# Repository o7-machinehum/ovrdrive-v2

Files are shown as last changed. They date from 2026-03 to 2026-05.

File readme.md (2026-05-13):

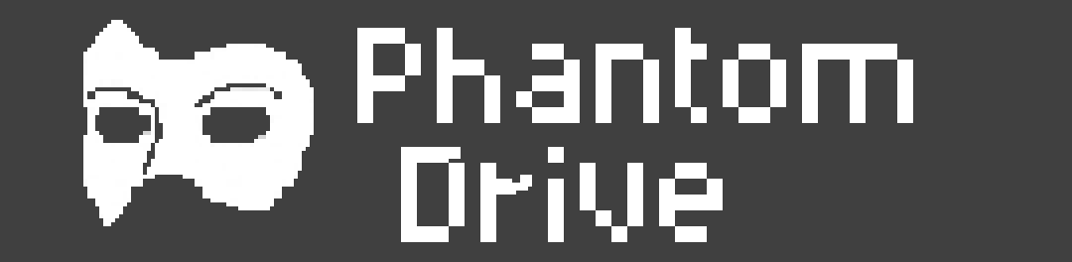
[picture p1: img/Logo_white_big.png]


Phantomdrive is open source encrypted USB drive with a stealth mechanism to hide its second partition. To decrypt it you must create a file called unlock.txt containing your password in the format `password:addpasswordhere`, this is used to derive a AES-256 key. The drive automatically unmounts itself, remounts the remaining disk and encrypts and decrypts in place. It uses CH569W SoC, which has USB3, SDIO and an AES hardware block. It is programmable over USB using the `wch-ch56x-isp` library.

``` bash
|-- ee             # Hardware files
|-- Makefile
|-- readme.md      # This files
|-- test           # Test the cypto components
|-- ref            # Reference docs
|-- src            # Firmware
|-- tests          # Verification scripts
|-- wch-ch56x-bsp  # Board support package
`-- wch-ch56x-isp  # Programming software
```

# Getting Started
``` bash
git submodule update --init --recursive --checkout --force
cd wch-ch56x-isp
make # Build the ISP tool
```

## Install the toolchain
The HydraUSB3 project requires a patched GCC that supports the
`WCH-Interrupt-fast` interrupt attribute. Download the xpack GCC from the HydraUSB3 project:

```bash
cd /tmp
curl -sL -o riscv-gcc-xpack.tar.gz \
  "https://github.com/hydrausb3/riscv-none-elf-gcc-xpack/releases/download/12.2.0-1/xpack-riscv-none-elf-gcc-12.2.0-1-linux-x64.tar.gz"
tar xzf riscv-gcc-xpack.tar.gz
sudo cp -r xpack-riscv-none-elf-gcc-12.2.0-1/* /usr/local/
```

## Debugging
```
make UART=1 # Enable UART
make UART=1 DEBUG_USB=1 # Enable USB Debugging
```

## Build and Flashing the project
``` bash
make
# Remove flash drive
# While holding boot button, plug in
./wch-ch56x-isp/wch-ch56x-isp -d=off # This is needed just one to disable debug mode
make flash
```

## Unlocking Drive
``` bash
sudo echo "password:YourPasswordHere13245" > /mnt/unlock.txt
```

# Releasing the hardware
``` bash
./scripts/release_hardware.sh
```

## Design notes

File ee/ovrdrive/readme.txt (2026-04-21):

Ovrdrive
--------
Size :	36.6 x 15 mm
Layer : 4 Layers
Material : FR-4: TG150
Thickness : 0.6 mm
Min track/spacing : 4/4mil
Min hole size : 0.2mm
Solder mask : Black
Silkscreen : White
Edge connector : No
Surface finish : HASL lead free
Via process : Tenting vias
Finished copper : 1 oz Cu (Inner Copper:1 oz)
Remove product No. : Yes

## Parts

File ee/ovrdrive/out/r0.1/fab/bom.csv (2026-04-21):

Designator | Value | Footprint | Quantity | Part Number
C1,C2,C5-C7,C9,C11-C13 | 22uF | Capacitor_SMD:C_0402_1005Metric | 9 | CL05A226MQ5N6J8
C3,C4,C8,C10,C14-C18,C21-C23,C26-C28 | 100nF | Capacitor_SMD:C_0402_1005Metric | 15 | CL05B104KP5NNNC
C19,C20 | 15pF | Capacitor_SMD:C_0402_1005Metric | 2 | CL05C150JB5NNNC
C24,C25 | 2.2uF | Capacitor_SMD:C_0402_1005Metric | 2 | CL05A225MQ5NNNC
J2 | USB3_A | Connector_USB:USB3_A_Plug_Wuerth_692112030100_Horizontal | 1 | 692112030100
J4 | Micro_SD_Card_Det_Hirose_DM3AT | Connector_Card:microSD_HC_Hirose_DM3AT-SF-PEJM5 | 1 | DM3AT-SF-PEJM5
L1,L2 | 2.2uH | Inductor_SMD:L_Changjiang_FTC303015D | 2 | SRN3015-2R2M
R1,R2,R4,R5 | 100k | Capacitor_SMD:C_0402_1005Metric | 4 | RC0402FR-07100KL
R3 | 450k | Capacitor_SMD:C_0402_1005Metric | 1 | RC0402FR-07453KL
RN1,RN2 | 47k | Resistor_SMD:R_Array_Concave_4x0402 | 2 | CAT10-473J4LF
SW1 | SW_Push | Button_Switch_SMD:SW_Push_SPST_NO_Alps_SKRK | 1 | SKRKAEE020
U1 | CH569W | Package_DFN_QFN:QFN-68-1EP_8x8mm_P0.4mm_EP5.2x5.2mm | 1 | CH569W
U2,U3 | TLV62569DBV | Package_TO_SOT_SMD:SOT-23-5 | 2 | TLV62569DBV
Y2 | 30Mhz | Crystal:Crystal_SMD_3225-4Pin_3.2x2.5mm | 1 | ABM8-30.000MHZ-12-B1U-T

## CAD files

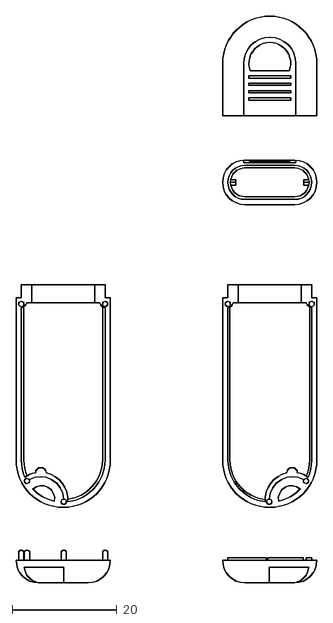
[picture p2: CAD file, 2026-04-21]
mech/LK-USB06.dxf
57.4 x 108.1

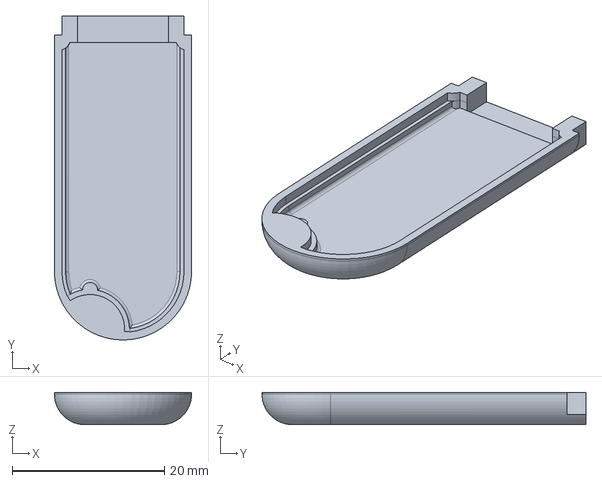
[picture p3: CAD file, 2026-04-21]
mech/case-Model.step
18.0 x 42.5 x 4.25 mm

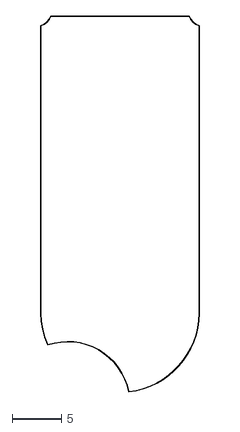
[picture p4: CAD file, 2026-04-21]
mech/LK-USB06_PCB_Outline.dxf
16.0 x 38.0

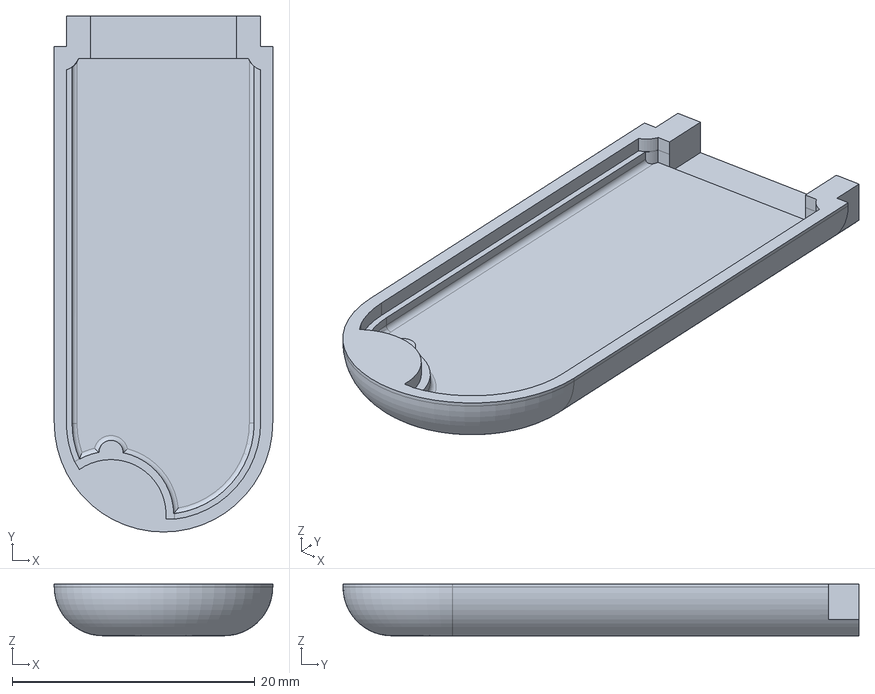
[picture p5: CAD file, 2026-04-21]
mech/case.FCStd
18.0 x 42.5 x 4.25 mm

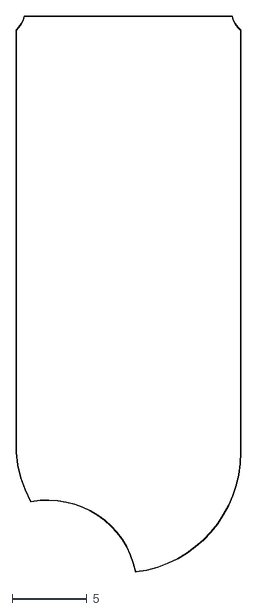
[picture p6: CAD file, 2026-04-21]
mech/outline-ModelSketch.dxf
15.0 x 37.2

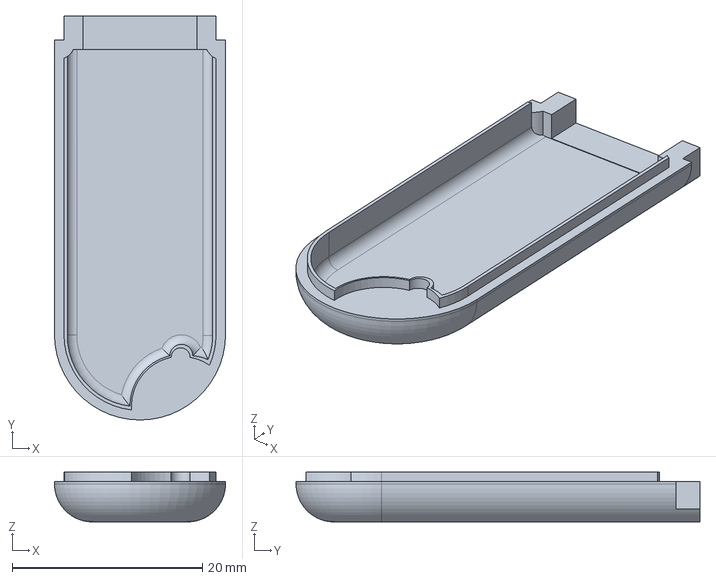
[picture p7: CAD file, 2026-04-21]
mech/case_top.FCStd
18.0 x 42.5 x 5.25 mm

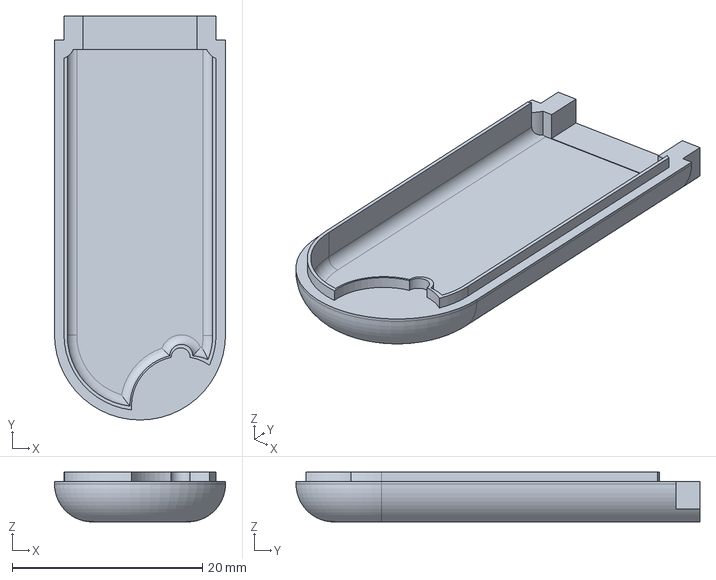
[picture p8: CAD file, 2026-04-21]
mech/case_top-Model.step
18.0 x 42.5 x 5.25 mm

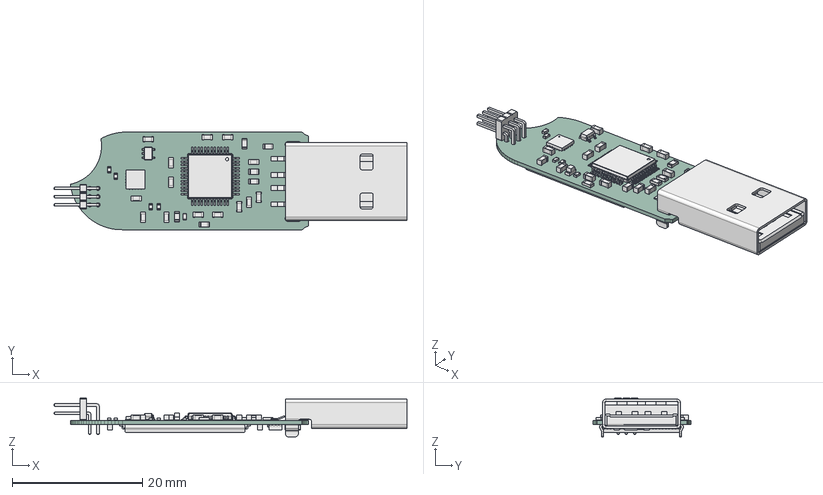
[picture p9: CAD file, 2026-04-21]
mech/pcb.FCStd
54.3 x 15.0 x 5.97 mm
ovrdrive PCB002

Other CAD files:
mech/LK-USB15.dwg
mech/LK-USB08.dwg
mech/LK-USB09.dwg
mech/LK-USB05.dwg
mech/LK-USB10.dwg
mech/ovrdrive.FCStd
mech/outline.FCStd
mech/LK-USB06.dwg

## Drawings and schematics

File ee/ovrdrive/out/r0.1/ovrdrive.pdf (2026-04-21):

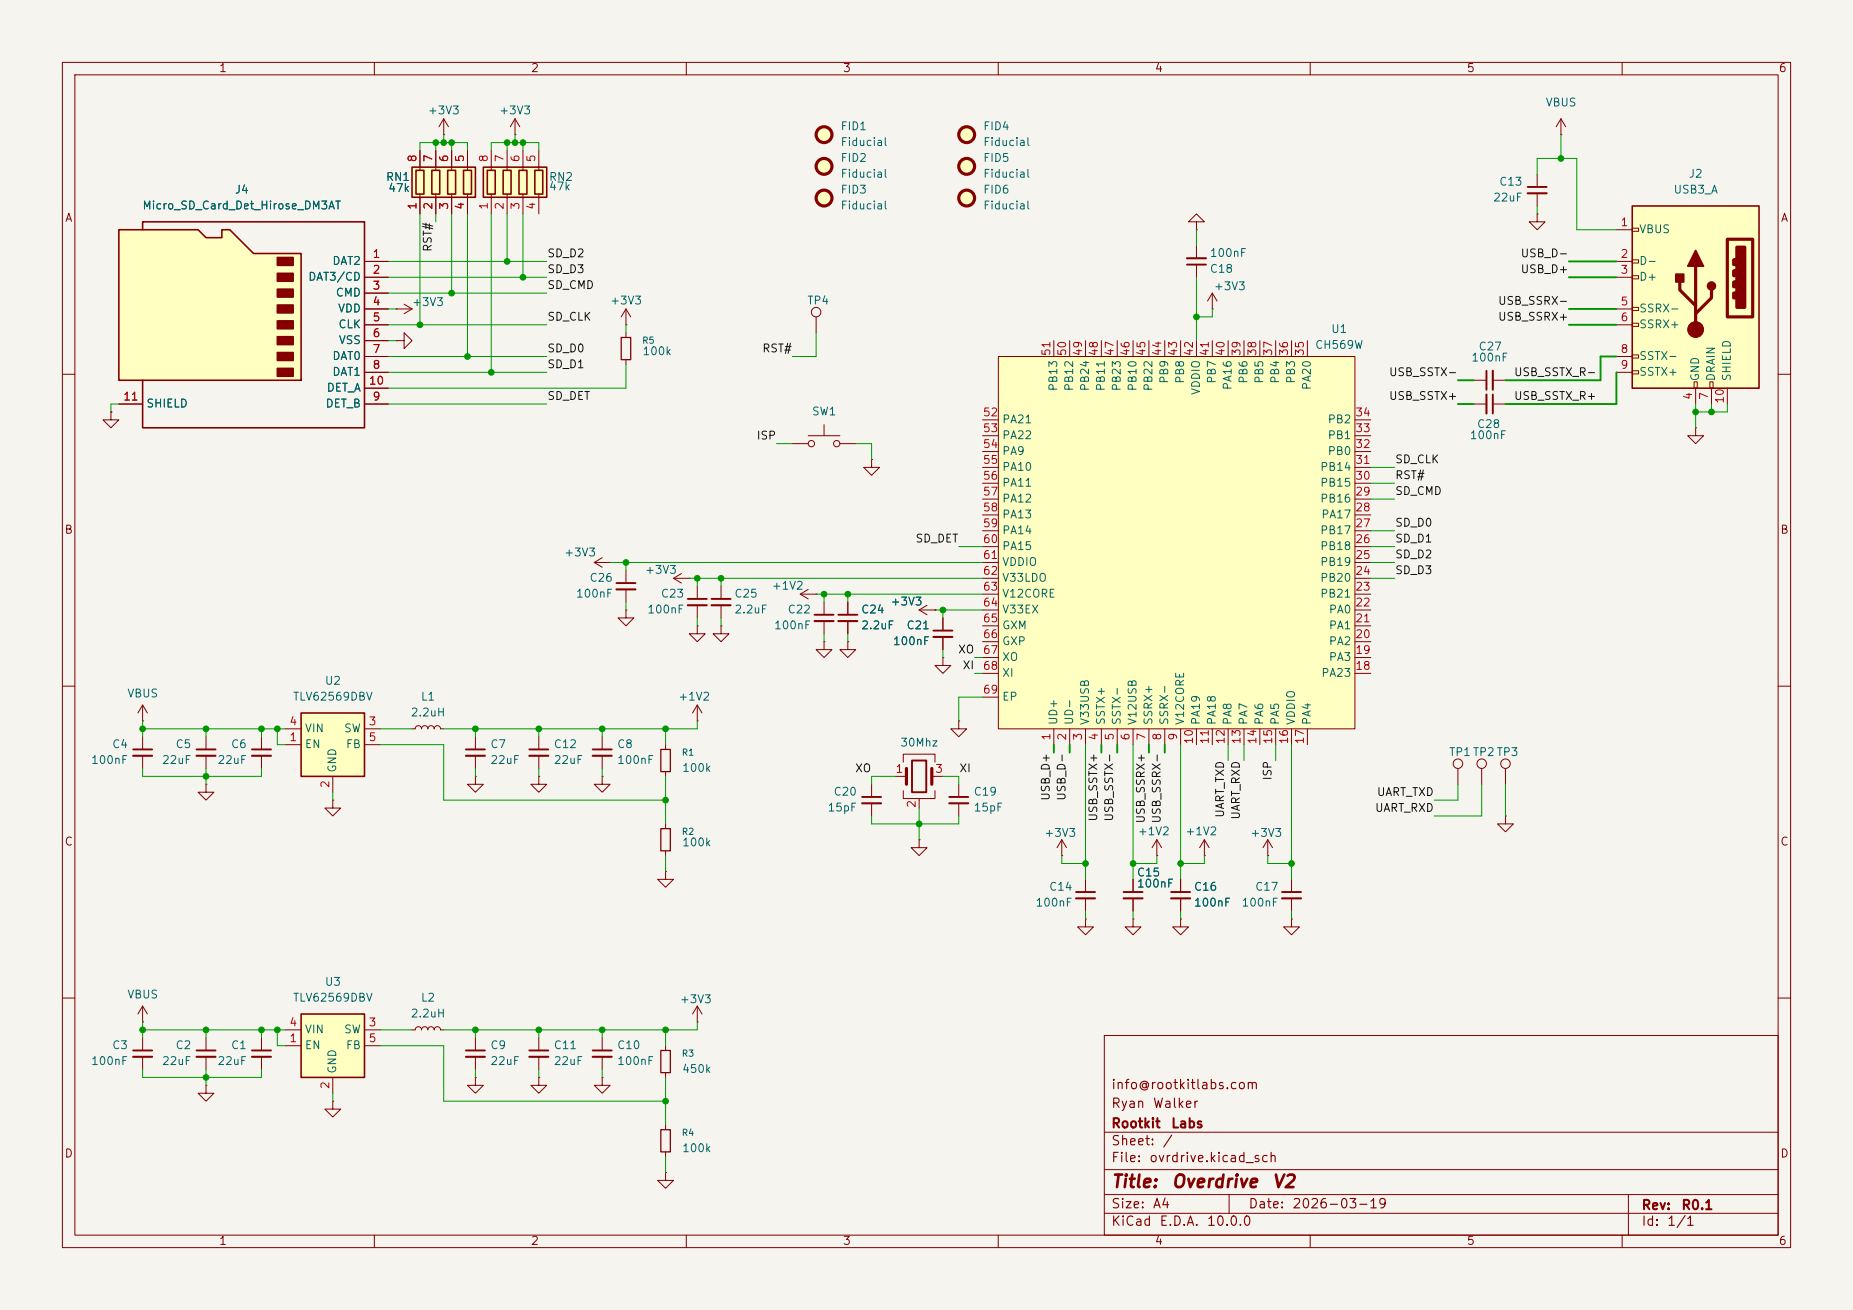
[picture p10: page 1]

info@rootkitlabs.com
Rootkit Labs Ryan Walker

Size: A4 | Rev: R0.1

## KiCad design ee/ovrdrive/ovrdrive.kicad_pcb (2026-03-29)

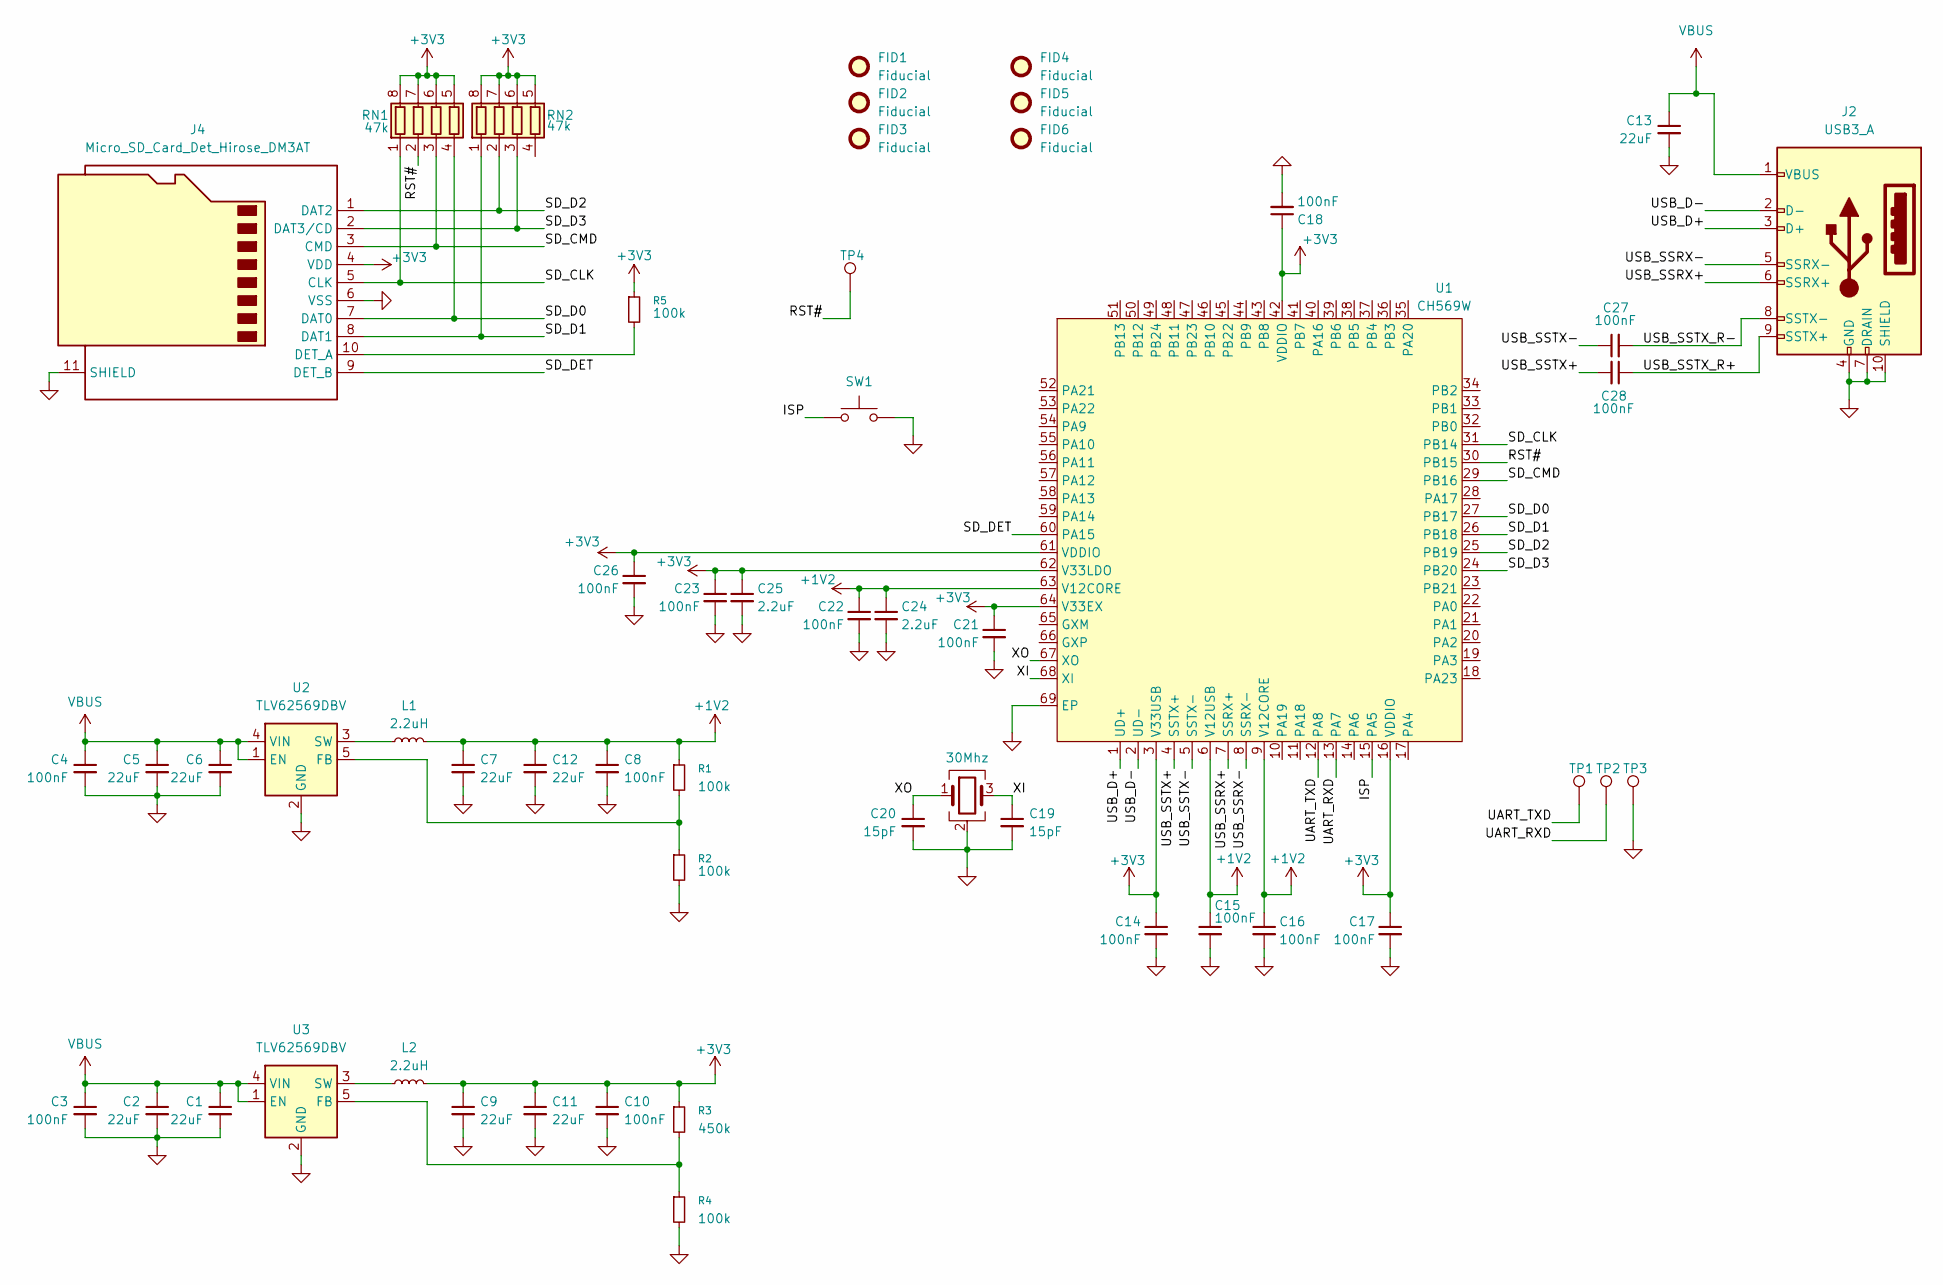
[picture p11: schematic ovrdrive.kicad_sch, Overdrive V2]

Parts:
C1, C2, C5, C6, C7, C9, C11, C12, C13: 22uF; C_0402_1005Metric; MPN CL05A226MQ5N6J8
C3, C4, C8, C10, C14, C15, C16, C17, C18, C21, C22, C23, C26, C27, C28: 100nF; C_0402_1005Metric; MPN CL05B104KP5NNNC
C19, C20: 15pF; C_0402_1005Metric; MPN CL05C150JB5NNNC
C24, C25: 2.2uF; C_0402_1005Metric; MPN CL05A225MQ5NNNC
FID1, FID2, FID3, FID4, FID5, FID6: Fiducial; Fiducial_0.5mm_Mask1mm; MPN DNP
J2: USB3_A; USB3_A_Plug_Wuerth_692112030100_Horizontal; MPN 692112030100
J4: Micro_SD_Card_Det_Hirose_DM3AT; microSD_HC_Hirose_DM3AT-SF-PEJM5; MPN DM3AT-SF-PEJM5
L1, L2: 2.2uH; L_Changjiang_FTC303015D; MPN SRN3015-2R2M
R1, R2, R4, R5: 100k; C_0402_1005Metric; MPN RC0402FR-07100KL
R3: 450k; C_0402_1005Metric; MPN RC0402FR-07453KL
RN1, RN2: 47k; R_Array_Concave_4x0402; MPN CAT10-473J4LF
SW1: SW_Push; SW_Push_SPST_NO_Alps_SKRK; MPN SKRKAEE020
TP1, TP2, TP3, TP4: TestPoint; TestPoint_Pad_1.0x1.0mm; MPN DNP
U1: CH569W; QFN-68-1EP_8x8mm_P0.4mm_EP5.2x5.2mm; MPN CH569W
U2, U3: TLV62569DBV; SOT-23-5; MPN TLV62569DBV
Y2: 30Mhz; Crystal_SMD_3225-4Pin_3.2x2.5mm; MPN ABM8-30.000MHZ-12-B1U-T

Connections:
+1V2: C7.1, C8.1, C12.1, C15.1, C16.1, C22.1, C24.1, L1.2, R1.1, U1.6 (V12USB), U1.9 (V12CORE), U1.63 (V12CORE)
+3V3: C9.1, C10.1, C11.1, C14.1, C17.1, C18.1, C21.1, C23.1, C25.1, C26.1, J4.4 (VDD), L2.2, R3.1, R5.1, RN1.5 (R4.2), RN1.6 (R3.2), RN1.7 (R2.2), RN1.8 (R1.2), RN2.5 (R4.2), RN2.6 (R3.2), RN2.7 (R2.2), RN2.8 (R1.2), U1.3 (V33USB), U1.16 (VDDIO), U1.42 (VDDIO), U1.61 (VDDIO), U1.62 (V33LDO), U1.64 (V33EX)
/ISP: SW1.1, U1.15 (PA5)
/RST#: RN1.2 (R2.1), TP4.1 (1_1), U1.30 (PB15)
/SD_CLK: J4.5 (CLK), RN1.1 (R1.1), U1.31 (PB14)
/SD_CMD: J4.3 (CMD), RN1.3 (R3.1), U1.29 (PB16)
/SD_D0: J4.7 (DAT0), RN1.4 (R4.1), U1.27 (PB17)
/SD_D1: J4.8 (DAT1), RN2.1 (R1.1), U1.26 (PB18)
/SD_D2: J4.1 (DAT2), RN2.2 (R2.1), U1.25 (PB19)
/SD_D3: J4.2 (DAT3/CD), RN2.3 (R3.1), U1.24 (PB20)
/SD_DET: J4.9 (DET_B), U1.60 (PA15)
/UART_RXD: TP2.1 (1_1), U1.13 (PA7)
/UART_TXD: TP1.1 (1_1), U1.12 (PA8)
/USB_D+: J2.3 (D+), U1.1 (UD+)
/USB_D-: J2.2 (D-), U1.2 (UD-)
/USB_SSRX+: J2.6 (SSRX+), U1.7 (SSRX+)
/USB_SSRX-: J2.5 (SSRX-), U1.8 (SSRX-)
/USB_SSTX+: C28.2, U1.4 (SSTX+)
/USB_SSTX-: C27.1, U1.5 (SSTX-)
/USB_SSTX_R+: C28.1, J2.9 (SSTX+)
/USB_SSTX_R-: C27.2, J2.8 (SSTX-)
/XI: C19.1, U1.68 (XI), Y2.3
/XO: C20.1, U1.67 (XO), Y2.1
GND: C1.2, C2.2, C3.2, C4.2, C5.2, C6.2, C7.2, C8.2, C9.2, C10.2, C11.2, C12.2, C13.2, C14.2, C15.2, C16.2, C17.2, C18.2, C19.2, C20.2, C21.2, C22.2, C23.2, C24.2, C25.2, C26.2, J2.4 (GND), J2.7 (DRAIN), J2.10 (SHIELD), J4.6 (VSS), J4.11 (SHIELD), R2.2, R4.2, SW1.2, TP3.1 (1_1), U1.69 (EP), U2.2 (GND), U3.2 (GND), Y2.2 (G), Y2.4 (G)
unnamed: J4.10 (DET_A), R5.2
unnamed: R1.2, R2.1, U2.5 (FB)
unnamed: L1.1, U2.3 (SW)
unnamed: R3.2, R4.1, U3.5 (FB)
unnamed: L2.1, U3.3 (SW)
VBUS: C1.1, C2.1, C3.1, C4.1, C5.1, C6.1, C13.1, J2.1 (VBUS), U2.1 (EN), U2.4 (VIN), U3.1 (EN), U3.4 (VIN)

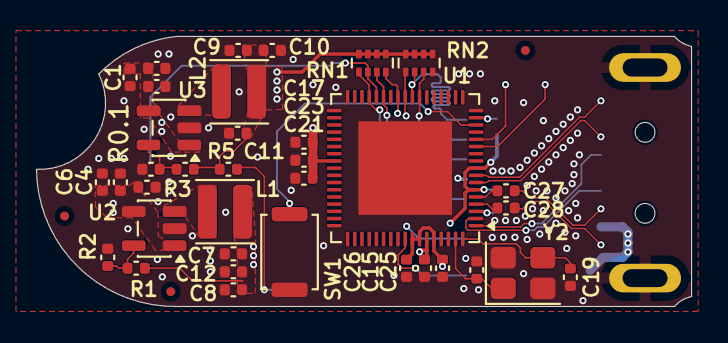
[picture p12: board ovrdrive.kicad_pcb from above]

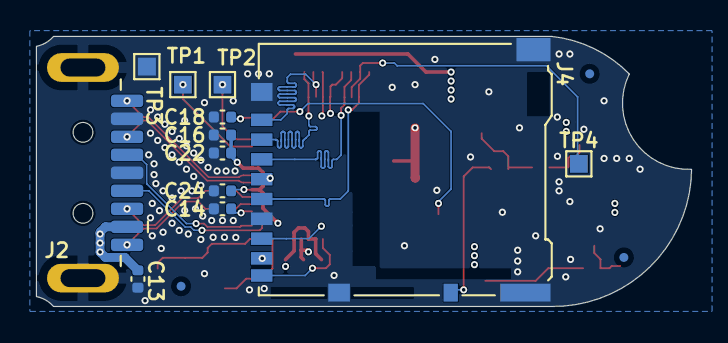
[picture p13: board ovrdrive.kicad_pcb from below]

Board: 4 copper layers, 36.4 x 15.0 mm, 54 parts (15 on the bottom side), 30 nets.

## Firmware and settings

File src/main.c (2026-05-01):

/* main.c - USB MSC device: Host <-> CH569 USB2/USB3 <-> SD card
 * SPDX-License-Identifier: Apache-2.0
 */
#include "CH56x_common.h"
#include "CH56x_debug_log.h"

#include "CH56x_usb30_devbulk.h"
#include "CH56x_usb20_devbulk.h"
#include "CH56x_usb30_devbulk_LIB.h"
#include "CH56x_usb_devbulk_desc_cmd.h"

#include "bot.h"
#include "sd.h"
#include "ovrdrive.h"

#undef FREQ_SYS
#define FREQ_SYS (120000000)

#if(defined DEBUG)
#define UART1_BAUD (115200)
#endif

#define BLINK_FAST (50)
#define BLINK_USB3 (250)
#define BLINK_USB2 (500)

int blink_ms = BLINK_USB2;

debug_log_buf_t log_buf;

#define FLASH_ROMA_UID_ADDR (0x77fe4)
usb_descriptor_serial_number_t unique_id;

usb_descriptor_usb_vid_pid_t vid_pid =
{
	.vid = { .id_16b = 0x16C0 },
	.pid = { .id_16b = 0x05DC }
};

/* Init: GPIO/BSP -> UART -> USB -> SD -> main loop (bot_poll) */
int main()
{
	bsp_gpio_init();
	bsp_init(FREQ_SYS);
	log_init(&log_buf);

#if(defined DEBUG)
	UART1_init(UART1_BAUD, FREQ_SYS);
#endif
	log_printf("Phantomdrive, ChipID(Hex)=%02X\r\n", SYS_GetChipID());

	memset(&unique_id, 0, 8);
	FLASH_ROMA_READ(FLASH_ROMA_UID_ADDR, (uint32_t*)&unique_id, 8);

	log_printf("Phantomdrive FW v0.1 (CPr Freq=%d MHz)\r\n", (FREQ_SYS/1000000));

	R32_USB_CONTROL = 0;
	PFIC_EnableIRQ(USBSS_IRQn);
	PFIC_EnableIRQ(LINK_IRQn);

	/* Timer0: USB3 link training timeout, falls back to USB2 */
	PFIC_EnableIRQ(TMR0_IRQn);
	R8_TMR0_INTER_EN = RB_TMR_IE_CYC_END;
	TMR0_TimerInit(67000000);

	usb_descriptor_set_string_serial_number(&unique_id);
	usb_descriptor_set_usb_vid_pid(&vid_pid);
	USB30D_init(ENABLE);

	log_printf("Initializing SD card...\r\n");
	uint8_t sta = SDCardInit(&TF_EMMCParam);

	/* Enable eMMC error IRQ after init (BKGAP/TRANDONE polled in data path) */
	PFIC_EnableIRQ(EMMC_IRQn);
	TF_EMMCParam.EMMCOpErr = 0;

	if(sta == OP_SUCCESS)
	{
		g_bot.device_ready |= BOT_FLAG_DEVICE_READY;
		log_printf("SD OK: %d sectors (%d MB)\r\n",
			TF_EMMCParam.EMMCSecNum,
			TF_EMMCParam.EMMCSecNum / 2048);
		ovrd_init();
	}
	else
	{
		log_printf("SD init FAILED (sta=%d)\r\n", sta);
	}

	log_printf("MSC ready\r\n");
	while(1)
	{
		bot_poll();
	}
}

__attribute__((interrupt("WCH-Interrupt-fast"))) void HardFault_Handler(void)
{
	printf("HardFault\r\n");
	printf(" SP=0x%08X\r\n", __get_SP());
	printf(" MIE=0x%08X\r\n", __get_MIE());
	printf(" MSTATUS=0x%08X\r\n", __get_MSTATUS());
	printf(" MCAUSE=0x%08X\r\n", __get_MCAUSE());
	bsp_wait_ms_delay(1);
}

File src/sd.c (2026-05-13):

/********************************** (C) COPYRIGHT *******************************
 * File Name          : sd.c
 * Description        : SD card initialization driver
 *
 * This file implements SD card initialization using the CH569's eMMC controller.
 * The CH569 has a single "eMMC" controller that handles both eMMC and SD cards.
 * SD cards use a different init sequence than eMMC, so this file provides
 * SD-specific versions of OCR reading, RCA assignment, CSD parsing, etc.
 *
 * The init sequence follows the SD Physical Layer Spec (Section 4.2):
 *   CMD0 (reset) → CMD8 (voltage check) → ACMD41 (capacity negotiation) →
 *   CMD2 (read CID) → CMD3 (get RCA) → CMD9 (read CSD) → CMD7 (select) →
 *   ACMD6 (set 4-bit bus) → ACMD51 (read SCR)
 *
 * After init, the card is in Transfer State and ready for data commands
 * (CMD17/18 for read, CMD24/25 for write).
 *
 * Hardware interface:
 *   CLK  = PB15 (bSDCK)          - SD clock output
 *   CMD  = PB14 (bSDCMD)         - SD command line (bidirectional)
 *   DAT0 = PB17                  - SD data line 0
 *   DAT1 = PB18                  - SD data line 1
 *   DAT2 = PB19                  - SD data line 2
 *   DAT3 = PB20                  - SD data line 3
 *   [CH569DS1.PDF: GPIO Pin Multiplexing, eMMC Controller]
 *
 * Clock configuration:
 *   Base clock = 480MHz (from PLL)
 *   LOWEMMCCLK divider = 0x1F (31) → 480/31 ≈ 15MHz
 *   Used during init (slow) and currently for data transfers too
 *   (conservative speed for long-wire setups)
 *   [ref/SD_Physical_Layer_Spec_v6.00.pdf: Section 6 - Clock Control]
 *
 * SPDX-License-Identifier: Apache-2.0
 *******************************************************************************/
#include "sd.h"

/* Scratch buffer for SCR register read (8 bytes needed, 512 allocated for
 * DMA alignment requirements). Must be in RAMX for DMA access.
 * [CH569DS1.PDF: DMA buffers must be in RAMX (.DMADATA section)] */
static __attribute__((aligned(8))) uint8_t scr_buf[512] __attribute__((section(".DMADATA")));

/*******************************************************************************
 * SDReadOCR - Read SD card Operating Conditions Register via ACMD41
 *
 * SD cards use ACMD41 (CMD55 prefix + CMD41) instead of CMD1 (eMMC).
 * This negotiates voltage range and determines card capacity type.
 *
 * The host sends:
 *   CMD55 (APP_CMD prefix, tells card next command is application-specific)
 *   ACMD41 with arg 0x40FF8000:
 *     Bit 30 (HCS=1): Host supports SDHC/SDXC
 *     Bits 23-0: Voltage window (3.2-3.4V range)
 *
 * Card responds with OCR register:
 *   Bit 31: Power-up complete (busy bit, polled until set)
 *   Bit 30: Card Capacity Status (CCS): 1=SDHC/SDXC, 0=SDSC
 *
 * [ref/SD_Physical_Layer_Spec_v6.00.pdf: Section 4.2.3 - ACMD41]
 ******************************************************************************/
uint8_t SDReadOCR(PSD_PARAMETER pEMMCPara)
{
	uint8_t  i;
	uint32_t cmd_arg_val;
	uint16_t cmd_set_val;
	uint8_t  sta = 0;
	uint32_t cmd_rsp_val;

	/* Poll ACMD41 up to 100 times (~2 seconds total with delays).
	 * SD spec requires at most 1 second for power-up. */
	for(i = 0; i < 100; i++)
	{
		/* CMD55 - APP_CMD prefix (required before every ACMD)
		 * [ref/SD_Physical_Layer_Spec_v6.00.pdf: Section 4.3.9 - CMD55] */
		cmd_arg_val = 0;
		cmd_set_val = RB_EMMC_CKIDX | RB_EMMC_CKCRC | RESP_TYPE_48 | 55;
		EMMCSendCmd(cmd_arg_val, cmd_set_val);
		mDelayuS(2);
		while(1)
		{
			sta = CheckCMDComp(pEMMCPara);
			if(sta != CMD_NULL) break;
		}
		if(sta == CMD_FAILED)
		{
			mDelaymS(20);
			continue;
		}

		/* ACMD41 - SD_SEND_OP_COND
		 * Arg: 0x40FF8000 = HCS bit set + voltage window
		 * No CRC/index check on response (R3 response type) */
		cmd_arg_val = 0x40FF8000;
		cmd_set_val = RESP_TYPE_48 | 41;
		EMMCSendCmd(cmd_arg_val, cmd_set_val);
		mDelayuS(2);
		while(1)
		{
			sta = CheckCMDComp(pEMMCPara);
			if(sta != CMD_NULL) break;
		}
		if(sta == CMD_SUCCESS)
		{
			/* Read OCR from response register
			 * [CH569DS1.PDF: R32_EMMC_RESPONSE3 holds R3/R1 response] */
			cmd_rsp_val = R32_EMMC_RESPONSE3;
			if(cmd_rsp_val & (1<<31))  /* Bit 31: power-up complete */
			{
				if(cmd_rsp_val & (1<<30))  /* Bit 30: CCS - SDHC/SDXC */
					pEMMCPara->EMMCType = EMMCIO_HIGH_CAPACITY_SD_CARD;
				else
					pEMMCPara->EMMCType = EMMCIO_CAPACITY_SD_CARD_V2_0;
				break;
			}
		}
		mDelaymS(20);
	}
	if(i == 100) return OP_FAILED;
	return sta;
}

/*******************************************************************************
 * SDSetRCA - Get Relative Card Address (CMD3)
 *
 * For SD cards, CMD3 (SEND_RELATIVE_ADDR) causes the card to publish its
 * own RCA. This differs from eMMC where the host assigns the RCA.
 * The RCA is in bits [31:16] of the R6 response.
 *
 * [ref/SD_Physical_Layer_Spec_v6.00.pdf: Section 4.3.1 - CMD3]
 ******************************************************************************/
uint8_t SDSetRCA(PSD_PARAMETER pEMMCPara)
{
	uint32_t cmd_arg_val;
	uint16_t cmd_set_val;
	uint8_t  sta;

	/* For SD cards, CMD3 arg is 0 (card chooses its own RCA) */
	cmd_arg_val = 0;
	cmd_set_val = RB_EMMC_CKIDX | RB_EMMC_CKCRC | RESP_TYPE_48 | EMMC_CMD3;
	EMMCSendCmd(cmd_arg_val, cmd_set_val);
	while(1)
	{
		sta = CheckCMDComp(pEMMCPara);
		if(sta != CMD_NULL) break;
	}
	if(sta == CMD_SUCCESS)
	{
		/* Extract RCA from upper 16 bits of R6 response */
		pEMMCPara->EMMC_RCA = R32_EMMC_RESPONSE3 >> 16;
	}
	return sta;
}
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

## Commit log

2026-03-07 MSD works, issues with device showing up as disk.
    [main.c, sd.c]
2026-03-07 MSD working, issues sorted out
    [sd.c]
2026-03-26 The disk encryption worked once, but now trying again it didn't.
    [main.c, speed_test.py]
2026-03-26 Added reference material.
2026-03-29 Added ee files for drive.
    [ovrdrive.kicad_pcb, ovrdrive.kicad_sch]
2026-03-29 Finished routing of PCB.
    [ovrdrive.kicad_pcb, ovrdrive.kicad_sch]
2026-03-29 Added release script
    [ovrdrive.kicad_sch]
2026-03-29 Fixed SDIO pinout, length matched SDIO traces.
    [ovrdrive.kicad_pcb, ovrdrive.kicad_sch]
2026-04-21 Added mech files (from overdrive r1), refactored source code, released r0.1 PCB (at fab)
    [LK-USB05.dwg, LK-USB06.dwg, LK-USB06.dxf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]
